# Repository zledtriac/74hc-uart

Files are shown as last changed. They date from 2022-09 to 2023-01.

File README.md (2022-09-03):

# 74hc-uart
In this project, you can find a schematics and descriptions for an asynchronous serial transmitter and receiver with 74hcxxx ICs. The circuits can be used for diy and old cpus where there is no support for UART, or you can just check the schematics to get an idea how an UART could be implemented in microcontrollers. It could be useful for VHDL designs.

## Transmitter
You can find the schematics and a detailed description of the serial transmitter in the ./hardware/transmitter folder.

## Receiver
Coming soon!

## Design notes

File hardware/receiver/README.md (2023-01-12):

# Receiver
This is the receiver. It's only consists of 6 ICs. Actually 5 because U6 the 74HC244 IC can be left out, but with the current configuration it can 
be operated manually for demonstrations.

The receiver can receive a serial data transmission with **1 start bit, 8bit data without parity and 1 stop bit** on the end, with 9600 baude rate.

## Operation
The receiver has 3 pin headers for selecting the mode of operation (J4, J5, J6), before powering the receiver up, **please check the jumper positions, 
because the receiver can't operate in a circuit if the receiver is in manual operation mode.**

The receiver needs a 5V power supply to work, the power pins can be found on the Control header (J2) pin 1 - VCC, pin 2 - GND. After powering up the
receiver, due to the random behaviour of the U5A and U5B (74HC74) D flip-flops, it is possible that the cicuit will load a random data in the output 
register. It is recommanded to wait one full transmition time after power up and read the output register in order to clear the data ready signaling 
U5B D flip-flop.

The Control header (J2) has two other pins for control, pin 4 - !RD, and pin 7 - Ready. The !RD is an active-low input and this input enables the 
output shift register's tri-state output drivers so the received data will be present on the output.
The Ready is an output which will turns on when the data is received and ready to read.

When the RX input goes low, it will start the colock divider and if the input is held low for more than half the time of one bit then U5B (74HC74) 
D flip-flop will be set, and the Input trigger will lock on the signal and keeps the clock divider running. When the clock divider is running it means 
that the Bit counter and the Output shift register will receive a clock signal, and the data reception sequence is in progress. When the Q3 output on 
the Bit counter goes high, it will stops the Clock divider and the circuit will wait until the RX input goes back to high, and when the RX input went 
high it will resets the Input trigger and load the received data into the U4 (74HC595) output register and sets the U5A (74HC74) D flip-flop so the 
Ready output will turn to high.

The Output data register can be read at the same time when the data reception sequence is running because the output data register only updates when 
the data reception sequence is finished. But if the data is not readed befor the second reception finishes it will overwrite the data in the output 
register so the previous data will be lost.

## Manual operation
To use the circuit in a manual operation mode, set the jumper on the J5 pin header to enable the output of the U6 (74HC244) IC so the data on the 
output can be seen on the LED bar. If you want to use the button as a read signal then bridge the 1-2 pins on the J6 Mode select pin header. Or if you 
want to see the received data immediatelly, bridge the 3-4 pins in the J6 Mode select pin header.

## Oscillator
The oscillator is made out of two schmitt-triggered NAND gate of the U1 (74HC132) IC. With the 560pF C1 capacitor and the 10kOhm R1 plus the 10kOhm RV1 trimmer 
potentiometer this oscillator can be adjusted between 107kHz and 214kHz. The oscillator's frequency is not equal to the baud rate, because the sampling clock is
generated with the U2 (74HC191) counter IC which is in this case act as a clock divider. The Q3 output of the U2 (74HC191) IC will give a square wave signal with 
16th of the input frequency. So the equation for the baudrate is:
```
baud_rate = input_freq / 16
```
So the frequency of the oscillator should be 153.6kHz for a 9600 baud rate.\
For tuning the oscillator, a simple digital multimeter with frequency measuring capability is enough.

The J4 Clock select pin header can be used to fed external clock signal into the circuit. Just unplug the bridge from the 2-3 pins and connect the external clock 
signal the pin 3. The pin 4 can be used as a grounding point.

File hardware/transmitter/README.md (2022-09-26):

# Transmitter
This is the transmitter. It's only consists of 6 ICs. Actually 5 because U6 the 74HC244 IC can be left out, but with the current configuration it can 
be operated manually for demonstrations.

The transmitter transmits the data with **1 start bit, 8bit data without parity and 1 stop bit** on the end, with 9600 baud rate.

## Operation
The transmitter has 3 pin headers for selecting the mode of operation (J3, J5, J6), before powering the transmitter up, **please check the jumper positions, 
because the transmitter can't operate in a circuit if the transmitter is in manual operation mode.**

The transmitter needs a 5V power supply to work, the power pins can be found on the Control header (J4) pin 1 - VCC, pin 2 - GND. After powering up the
transmitter, due to the random behaviour of the set-reset latch made with the U5D and U5C NAND gate (74HC132) and of the U3A and U3B (74HC74) D flip-flops, 
it is possible that the cicuit will transmit a random data on the output.

*If this behaviour can cause issues in the target device, it is recommended to build
an output enable circuit after the U3B pin 9 output, which can be controlled by a switch, delay circuit or from software if the transmitter is connected to a CPU.*

The Control header (J4) has two other pins for control, pin 5 - !WR, and pin 8 - Busy. The !WR is an active-low input and this input starts the data transmission.
The Busy is an output which will be held high while the transmission is going (Short pulse section on *Figure 1.*), or while the !WR input is held low (Long pulse section on *Figure 1.*).

To send data, first set the data on the Data header (J1) then send a low pulse on the !WR pin. This will trigger the Input trigger circuitry. In this stage the output 
of the U5D will turn high, but since the U3A D flip-flop is not set, the inverted output of the U3A D flip-flop is also high, this will set the output of the U4A NAND 
gate to low, this will enables the load pins of the U1 (74HC165) shift register and the U2 (74HC191) counter IC, so the data will be loaded into the U1 shift register 
and the U2 counter IC will be set to 0. There is an extra bit made by the U4B NAND gate and the U3B D flip-flop, in the loading process it will set to one, this extra 
bit is the START bit. Since the U3A D flip-flop's clock input is connected to the main clock signal, the U3A D flip-flop will set and the inverted output of the U3A D 
flip-flop will turn to low.
After this, every clock pulse will shift out the data from U1 (74HC165) shift register, and increment the U2 (74HC191) counter until U2 (74HC191) counter reaches 8.
When the U2 (74HC191) counter reaches 8, the counting will stop and if the !WR input is high, it will reset the Input trigger circuitry, and after this, one clock 
pulse is needed to reset the U3A D flip-flop. So when the next write pulse comes in, the whole process will repeat.

<p align="center">

</p>

## Manual operation
To use the circuit in a manual operation mode, set the jumper on the J3 pin header to bridge the 1-2 pins, and on the J5 pin header to bridge the 2-3 pins. This will 
enables the U6 (74HC244) output so the data set by the SW1 dip switch will be put on the DATA input, and it will connect the SW2 button to the !WR input.
After the data set on the SW1 dip switch, the data sending can be initiated by pressing the SW2 button.

**please note that if the circuit is in manual operation mode, the DATA input will be driven by the U6 (74HC244) output and the !WR input will connected to the SW2 
button, so it can't be used in other circuits!**

## Oscillator
The oscillator is made out of two schmitt-triggered NAND gate of the U4 (74HC132) IC. With the 10nF C7 capacitor and the 10kOhm R5 plus the 10kOhm RV1 trimmer 
potentiometer this oscillator can be adjusted between 6kHz and 12kHz. The oscillator's frequency is equal to the baud rate, so for the 9600 baud rate set the 
oscillator to 9.6kHz. For the tuning, a simple digital multimeter with frequency measuring capability is enough.

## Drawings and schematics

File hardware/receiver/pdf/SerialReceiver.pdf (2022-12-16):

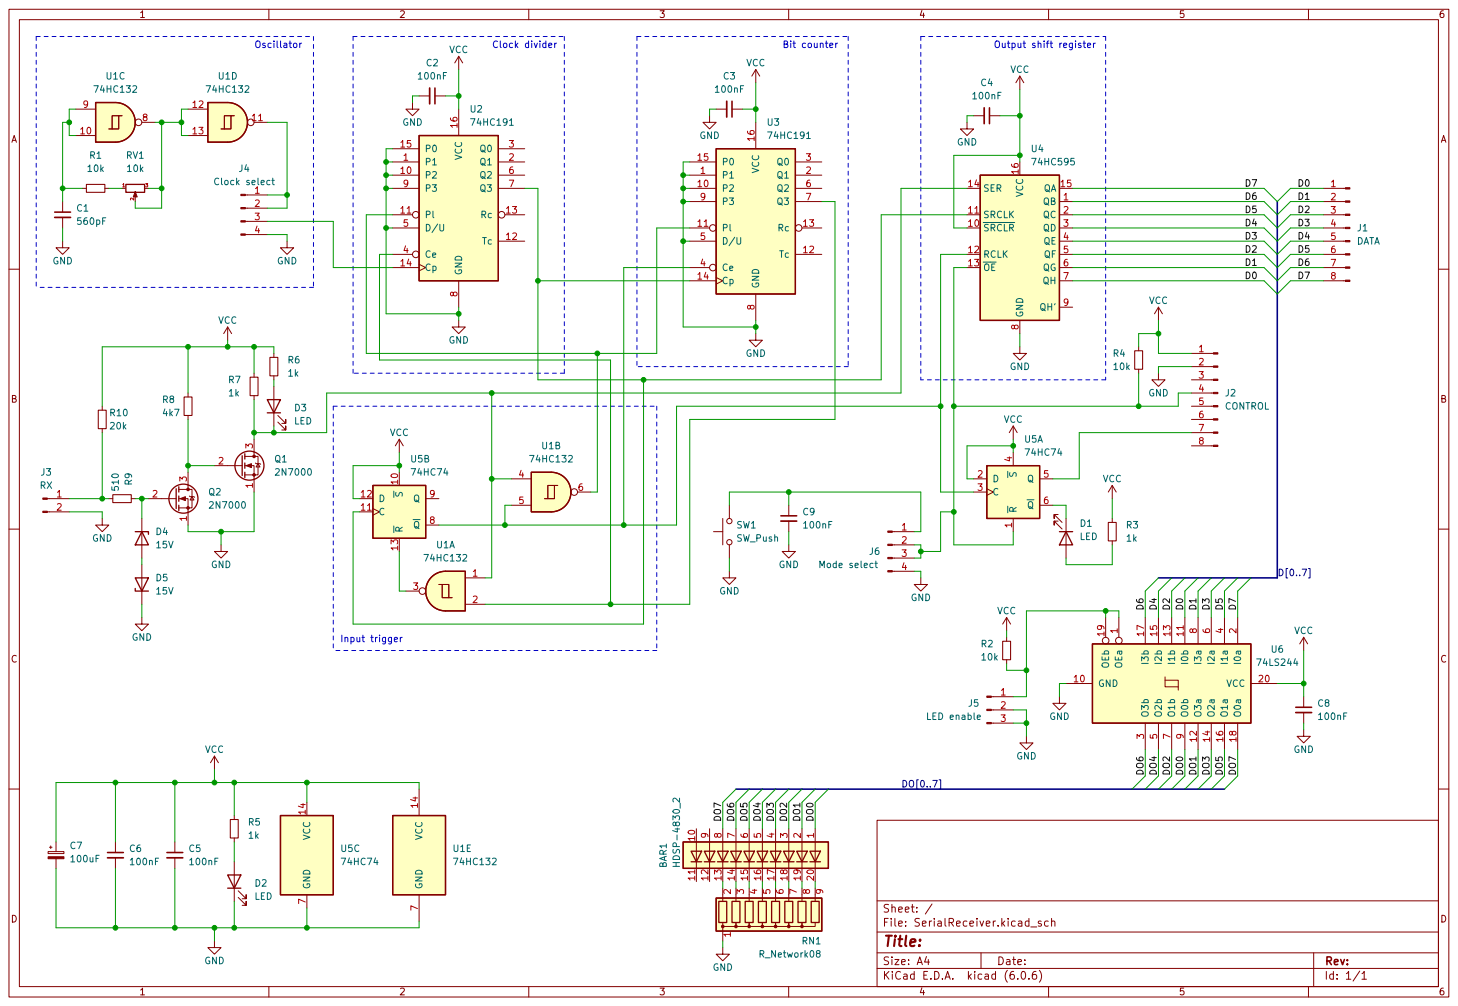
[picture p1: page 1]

File: SerialReceiver.kicad_sch Sheet: / VCC 14 GND

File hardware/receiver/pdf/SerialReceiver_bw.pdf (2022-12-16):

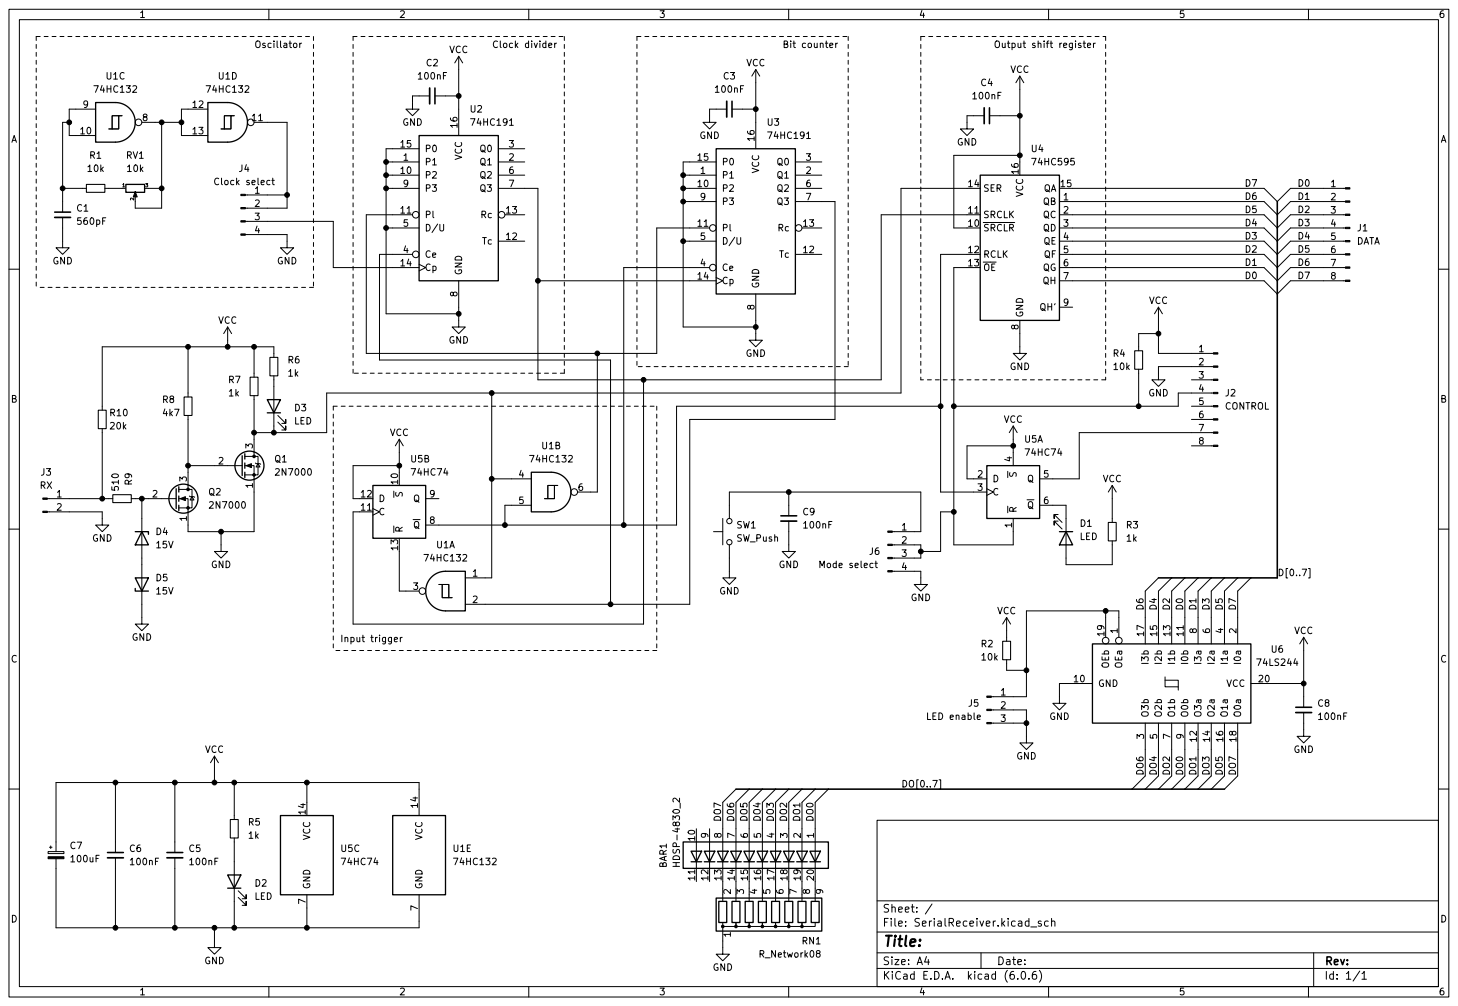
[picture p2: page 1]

File: SerialReceiver.kicad_sch Sheet: / VCC 14 GND

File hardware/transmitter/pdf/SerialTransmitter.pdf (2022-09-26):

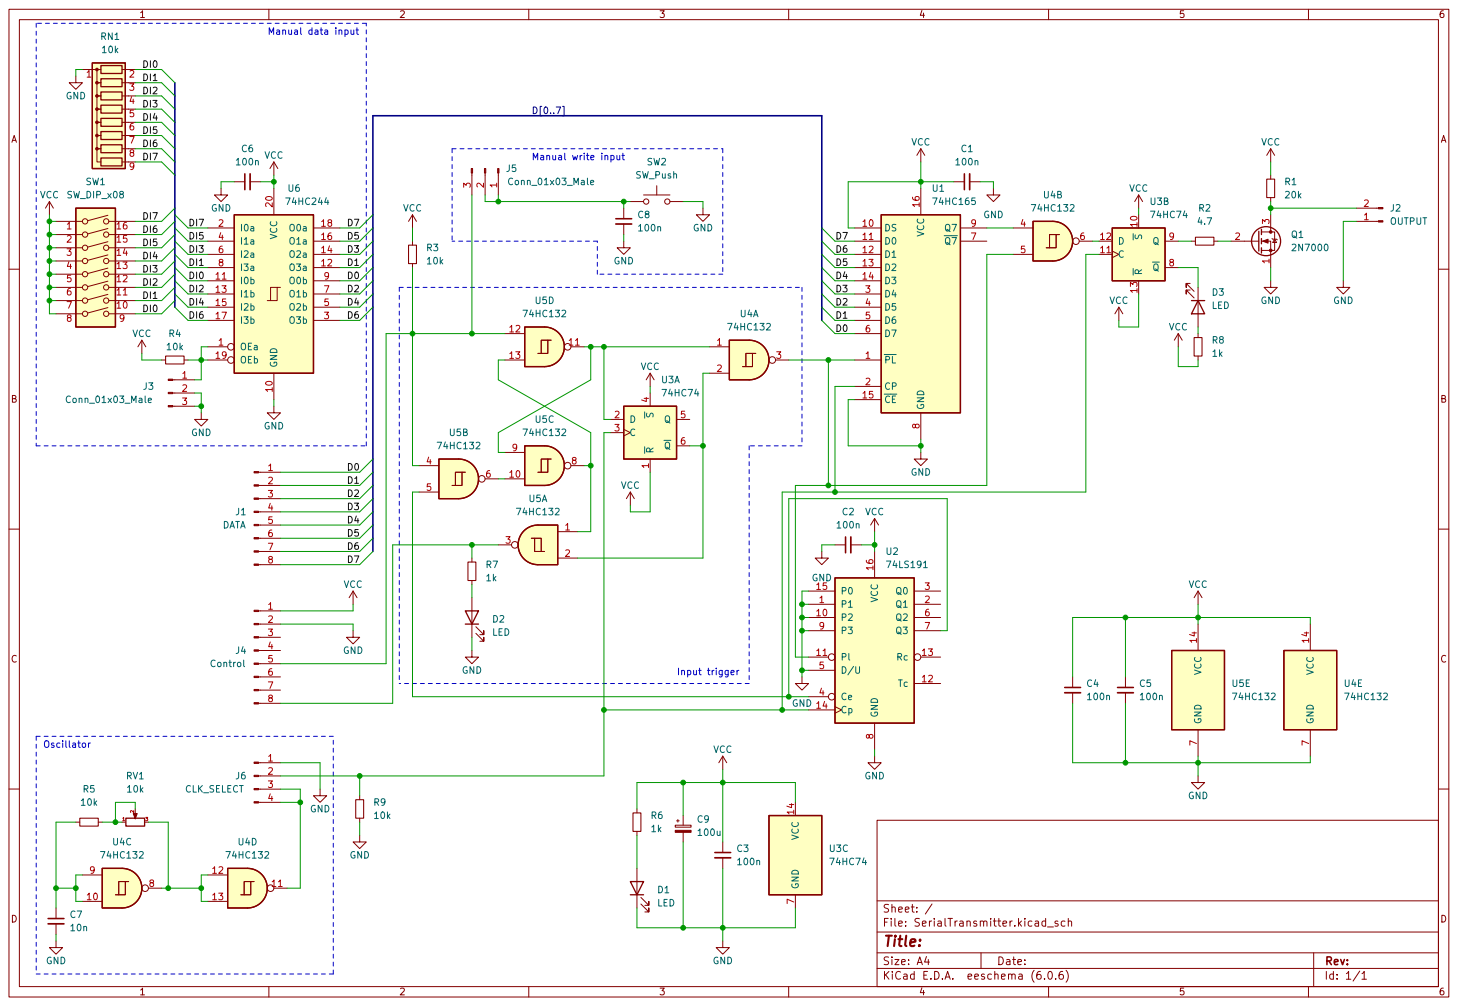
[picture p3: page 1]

File: SerialTransmitter.kicad_sch Sheet: / VCC

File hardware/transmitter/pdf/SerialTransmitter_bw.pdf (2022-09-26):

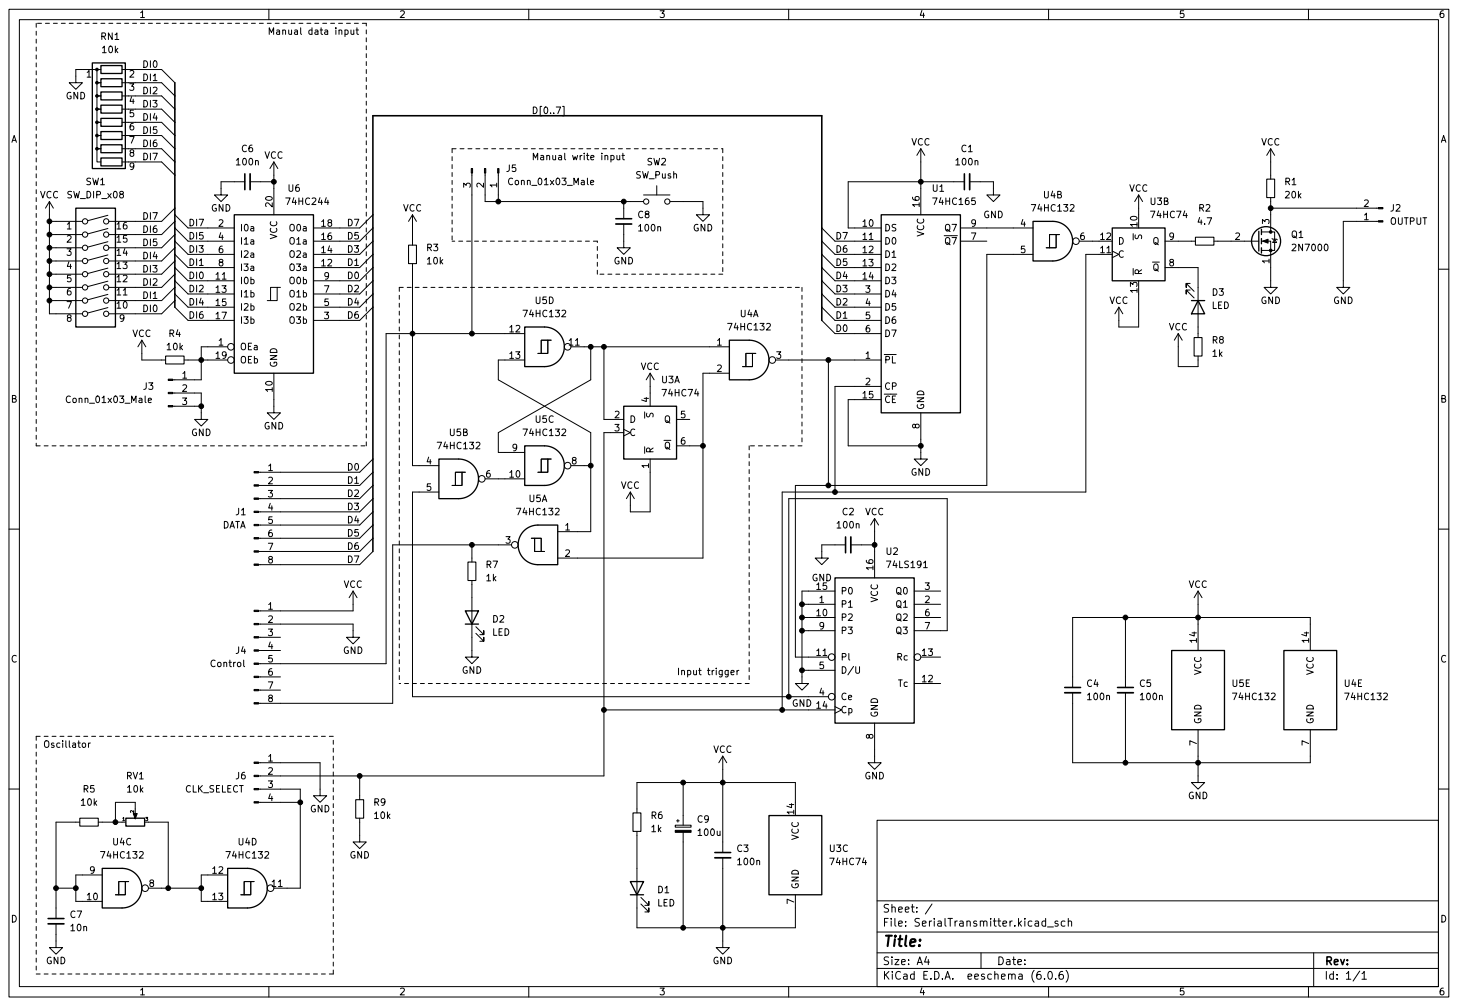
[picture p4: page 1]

File: SerialTransmitter.kicad_sch Sheet: / VCC

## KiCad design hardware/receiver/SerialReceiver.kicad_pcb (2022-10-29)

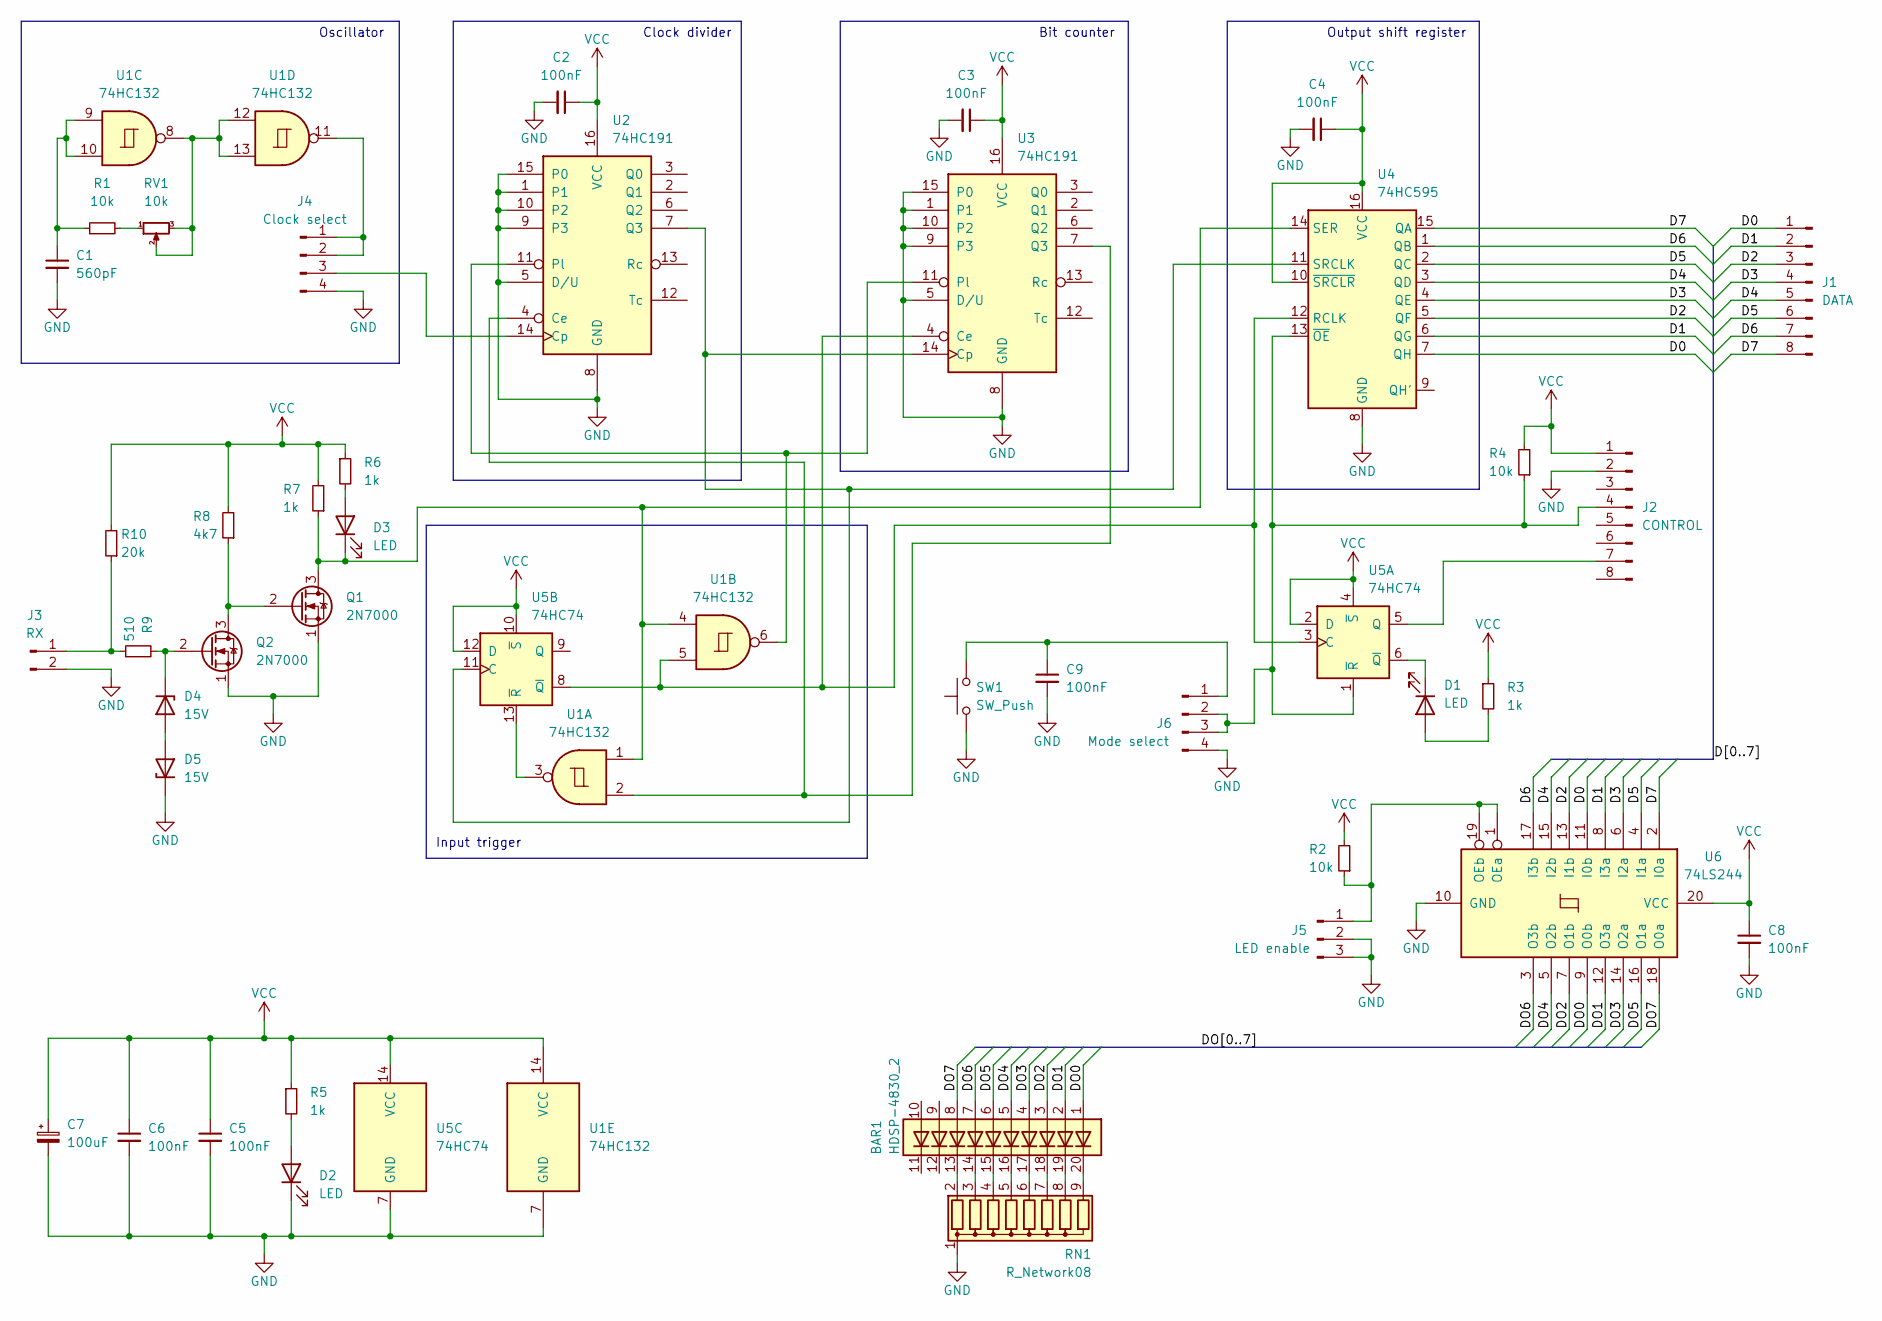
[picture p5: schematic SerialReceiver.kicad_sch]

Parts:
BAR1: HDSP-4830_2; DIP-20_W7.62mm_Socket
C1: 560pF; C_Disc_D3.0mm_W2.0mm_P2.50mm
C2, C3, C4, C5, C6, C8, C9: 100nF; C_Disc_D3.0mm_W2.0mm_P2.50mm
C7: 100uF; CP_Radial_D6.3mm_P2.50mm
D1, D2, D3: LED; LED_D3.0mm
D4, D5: 15V; D_DO-35_SOD27_P7.62mm_Horizontal
J1: DATA; PinHeader_1x08_P2.54mm_Horizontal
J2: CONTROL; PinHeader_1x08_P2.54mm_Horizontal
J3: RX; PinHeader_1x02_P2.54mm_Horizontal
J4: Clock select; PinHeader_1x04_P2.54mm_Vertical
J5: LED enable; PinHeader_1x03_P2.54mm_Vertical
J6: Mode select; PinHeader_1x04_P2.54mm_Vertical
Q1, Q2: 2N7000; TO-92_Inline_Wide
R1, R2, R4: 10k; R_Axial_DIN0207_L6.3mm_D2.5mm_P10.16mm_Horizontal
R3, R5, R6, R7: 1k; R_Axial_DIN0207_L6.3mm_D2.5mm_P10.16mm_Horizontal
R8: 4k7; R_Axial_DIN0207_L6.3mm_D2.5mm_P10.16mm_Horizontal
R9: 510; R_Axial_DIN0207_L6.3mm_D2.5mm_P10.16mm_Horizontal
R10: 20k; R_Axial_DIN0207_L6.3mm_D2.5mm_P10.16mm_Horizontal
RN1: R_Network08; R_Array_SIP9
RV1: 10k; Potentiometer_Bourns_3296W_Vertical
SW1: SW_Push; SW_PUSH_6mm
U1: 74HC132; DIP-14_W7.62mm
U2, U3: 74HC191; DIP-16_W7.62mm
U4: 74HC595; DIP-16_W7.62mm
U5: 74HC74; DIP-14_W7.62mm
U6: 74LS244; DIP-20_W7.62mm

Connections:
/D0: J1.1, U4.7 (QH), U6.11 (I0b)
/D1: J1.2, U4.6 (QG), U6.8 (I3a)
/D2: J1.3, U4.5 (QF), U6.13 (I1b)
/D3: J1.4, U4.4 (QE), U6.6 (I2a)
/D4: J1.5, U4.3 (QD), U6.15 (I2b)
/D5: J1.6, U4.2 (QC), U6.4 (I1a)
/D6: J1.7, U4.1 (QB), U6.17 (I3b)
/D7: J1.8, U4.15 (QA), U6.2 (I0a)
/DO0: BAR1.1 (A), U6.9 (O0b)
/DO1: BAR1.2 (A), U6.12 (O3a)
/DO2: BAR1.3 (A), U6.7 (O1b)
/DO3: BAR1.4 (A), U6.14 (O2a)
/DO4: BAR1.5 (A), U6.5 (O2b)
/DO5: BAR1.6 (A), U6.16 (O1a)
/DO6: BAR1.7 (A), U6.3 (O3b)
/DO7: BAR1.8 (A), U6.18 (O0a)
GND: C1.2, C2.2, C3.2, C4.2, C5.2, C6.2, C7.2, C8.2, C9.2, D2.1 (K), D5.1 (K), J2.2, J3.2, J4.4, J5.2, J5.3, J6.4, Q1.1 (S), Q2.1 (S), RN1.1 (common), SW1.1, U1.7 (GND), U2.1, U2.5 (D/U), U2.8 (GND), U2.9 (P3), U2.10 (P2), U2.15 (P0), U3.1, U3.5 (D/U), U3.8 (GND), U3.9 (P3), U3.10 (P2), U3.15 (P0), U4.8 (GND), U5.7 (GND), U6.10 (GND)
unnamed: BAR1.13 (K), RN1.2 (R1)
unnamed: BAR1.14 (K), RN1.3 (R2)
unnamed: BAR1.15 (K), RN1.4 (R3)
unnamed: BAR1.16 (K), RN1.5 (R4)
unnamed: BAR1.17 (K), RN1.6 (R5)
unnamed: BAR1.18 (K), RN1.7 (R6)
unnamed: BAR1.19 (K), RN1.8 (R7)
unnamed: BAR1.20 (K), RN1.9 (R8)
unnamed: C1.1, R1.1, U1.9, U1.10
unnamed: C9.1, J6.1, SW1.2
unnamed: D1.1 (K), U5.6 (~Q)
unnamed: D1.2 (A), R3.2
unnamed: D2.2 (A), R5.2
unnamed: D3.1 (K), Q1.3 (D), R7.1, U1.1, U1.4, U4.14 (SER)
unnamed: D3.2 (A), R6.2
unnamed: D4.1 (K), Q2.2 (G), R9.2
unnamed: D4.2 (A), D5.2 (A)
unnamed: J2.4, J6.2, J6.3, R4.1, U4.13 (~OE), U5.1 (~R)
unnamed: J2.7, U5.5 (Q)
unnamed: J3.1, R9.1, R10.1
unnamed: J4.1, J4.2, U1.11
unnamed: J4.3, U2.14 (Cp)
unnamed: J5.1, R2.1, U6.1 (OEa), U6.19 (OEb)
unnamed: Q1.2 (G), Q2.3 (D), R8.1
unnamed: R1.2, RV1.1
unnamed: U1.2, U2.4 (Ce), U3.7 (Q3)
unnamed: U1.3, U5.13 (~R)
unnamed: U1.5, U3.4 (Ce), U4.12 (RCLK), U5.3 (C), U5.8 (~Q)
unnamed: U1.6, U2.11 (Pl), U3.11 (Pl)
unnamed: RV1.2, RV1.3, U1.8, U1.12, U1.13
unnamed: U2.7 (Q3), U3.14 (Cp), U4.11 (SRCLK), U5.11 (C)
VCC: C2.1, C3.1, C4.1, C5.1, C6.1, C7.1, C8.1, J2.1, R2.2, R3.1, R4.2, R5.1, R6.1, R7.2, R8.2, R10.2, U1.14 (VCC), U2.16 (VCC), U3.16 (VCC), U4.10 (~SRCLR), U4.16 (VCC), U5.2 (D), U5.4 (~S), U5.10 (~S), U5.12 (D), U5.14 (VCC), U6.20 (VCC)

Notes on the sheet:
Bit counter
Clock divider
Oscillator
Output shift register
Input trigger

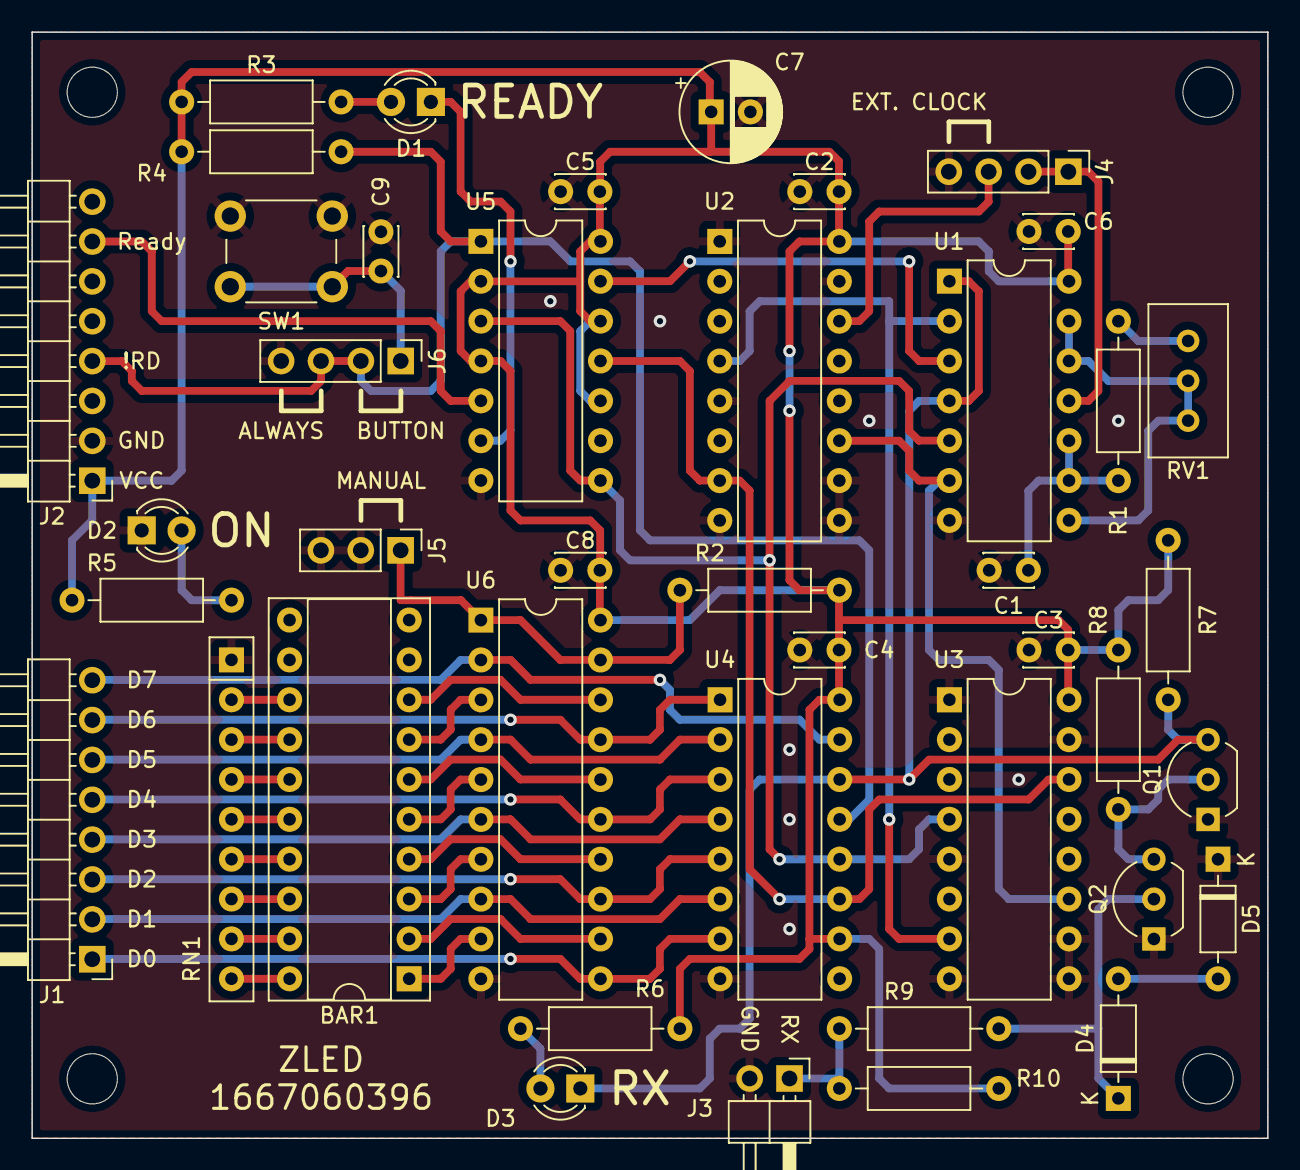
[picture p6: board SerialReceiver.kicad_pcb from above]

Board: 2 copper layers, 78.7 x 70.5 mm, 42 parts (0 on the bottom side), 49 nets.

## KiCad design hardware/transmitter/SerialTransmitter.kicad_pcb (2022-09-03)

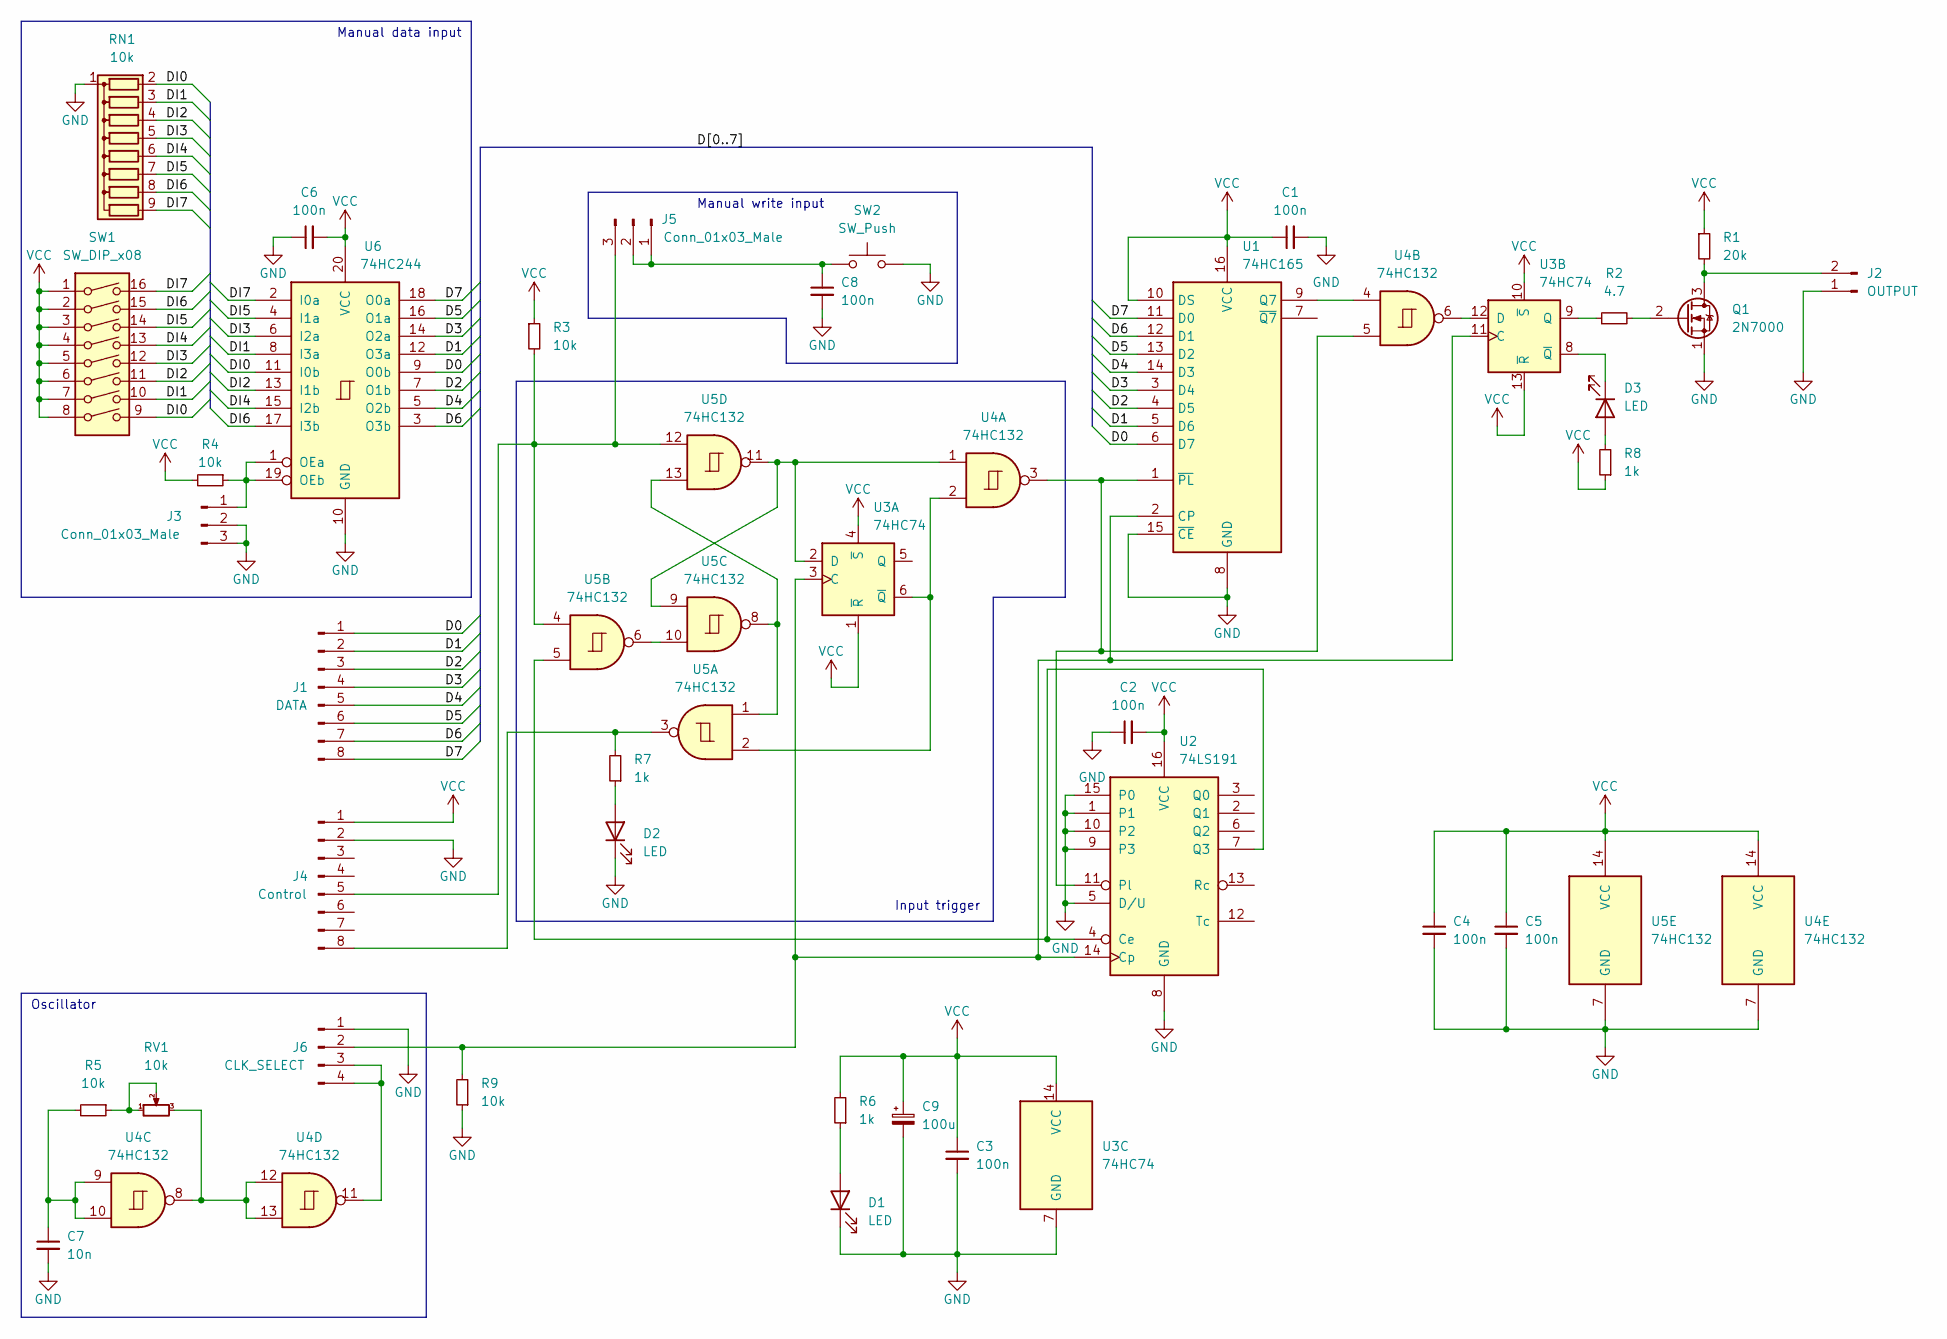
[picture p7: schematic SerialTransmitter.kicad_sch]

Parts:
C1, C2, C3, C4, C5, C6, C8: 100n; C_Disc_D3.0mm_W2.0mm_P2.50mm
C7: 10n; C_Disc_D3.0mm_W2.0mm_P2.50mm
C9: 100u; CP_Radial_D6.3mm_P2.50mm
D1, D2, D3: LED; LED_D3.0mm
J1: DATA; PinHeader_1x08_P2.54mm_Horizontal
J2: OUTPUT; PinHeader_1x02_P2.54mm_Horizontal
J3, J5: Conn_01x03_Male; PinHeader_1x03_P2.54mm_Vertical
J4: Control; PinHeader_1x08_P2.54mm_Horizontal
J6: CLK_SELECT; PinHeader_1x04_P2.54mm_Vertical
Q1: 2N7000; TO-92_Inline
R1: 20k; R_Axial_DIN0207_L6.3mm_D2.5mm_P10.16mm_Horizontal
R2: 4.7; R_Axial_DIN0207_L6.3mm_D2.5mm_P10.16mm_Horizontal
R3, R4, R5, R9: 10k; R_Axial_DIN0207_L6.3mm_D2.5mm_P10.16mm_Horizontal
R6, R7, R8: 1k; R_Axial_DIN0207_L6.3mm_D2.5mm_P10.16mm_Horizontal
RN1: 10k; R_Array_SIP9
RV1: 10k; Potentiometer_Bourns_3296W_Vertical
SW1: SW_DIP_x08; DIP-16_W7.62mm_Socket
SW2: SW_Push; SW_PUSH_6mm
U1: 74HC165; DIP-16_W7.62mm
U2: 74LS191; DIP-16_W7.62mm
U3: 74HC74; DIP-14_W7.62mm
U4, U5: 74HC132; DIP-14_W7.62mm
U6: 74HC244; DIP-20_W7.62mm

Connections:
/D0: J1.1, U1.6 (D7), U6.9 (O0b)
/D1: J1.2, U1.5 (D6), U6.12 (O3a)
/D2: J1.3, U1.4 (D5), U6.7 (O1b)
/D3: J1.4, U1.3 (D4), U6.14 (O2a)
/D4: J1.5, U1.14 (D3), U6.5 (O2b)
/D5: J1.6, U1.13 (D2), U6.16 (O1a)
/D6: J1.7, U1.12 (D1), U6.3 (O3b)
/D7: J1.8, U1.11 (D0), U6.18 (O0a)
/DI0: RN1.2 (R1), SW1.9, U6.11 (I0b)
/DI1: RN1.3 (R2), SW1.10, U6.8 (I3a)
/DI2: RN1.4 (R3), SW1.11, U6.13 (I1b)
/DI3: RN1.5 (R4), SW1.12, U6.6 (I2a)
/DI4: RN1.6 (R5), SW1.13, U6.15 (I2b)
/DI5: RN1.7 (R6), SW1.14, U6.4 (I1a)
/DI6: RN1.8 (R7), SW1.15, U6.17 (I3b)
/DI7: RN1.9 (R8), SW1.16, U6.2 (I0a)
unnamed: C7.1, R5.2, U4.9, U4.10
unnamed: C8.1, J5.1, J5.2, SW2.1
unnamed: D1.2 (A), R6.1
unnamed: D2.2 (A), R7.1
unnamed: D3.1 (K), U3.8 (~Q)
unnamed: D3.2 (A), R8.2
unnamed: J2.2, Q1.3 (D), R1.2
unnamed: J3.1, R4.1, U6.1 (OEa), U6.19 (OEb)
unnamed: J4.5, J5.3, R3.2, U5.4, U5.12
unnamed: J6.2, R9.2, U1.2 (CP), U2.14 (Cp), U3.3 (C), U3.11 (C)
unnamed: J6.3, J6.4, U4.11
unnamed: Q1.2 (G), R2.2
unnamed: R2.1, U3.9 (Q)
unnamed: R5.1, RV1.1, RV1.2
unnamed: J4.8, R7.2, U5.3
unnamed: RV1.3, U4.8, U4.12, U4.13
unnamed: U1.1 (~PL), U2.11 (Pl), U4.3, U4.5
unnamed: U1.9 (Q7), U4.4
unnamed: U2.4 (Ce), U2.7 (Q3), U5.5
unnamed: U3.2 (D), U4.1, U5.9, U5.11
unnamed: U3.6 (~Q), U4.2, U5.2
unnamed: U3.12 (D), U4.6
unnamed: U5.1, U5.8, U5.13
unnamed: U5.6, U5.10

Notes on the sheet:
Input trigger
Oscillator
Manual data input
Manual write input

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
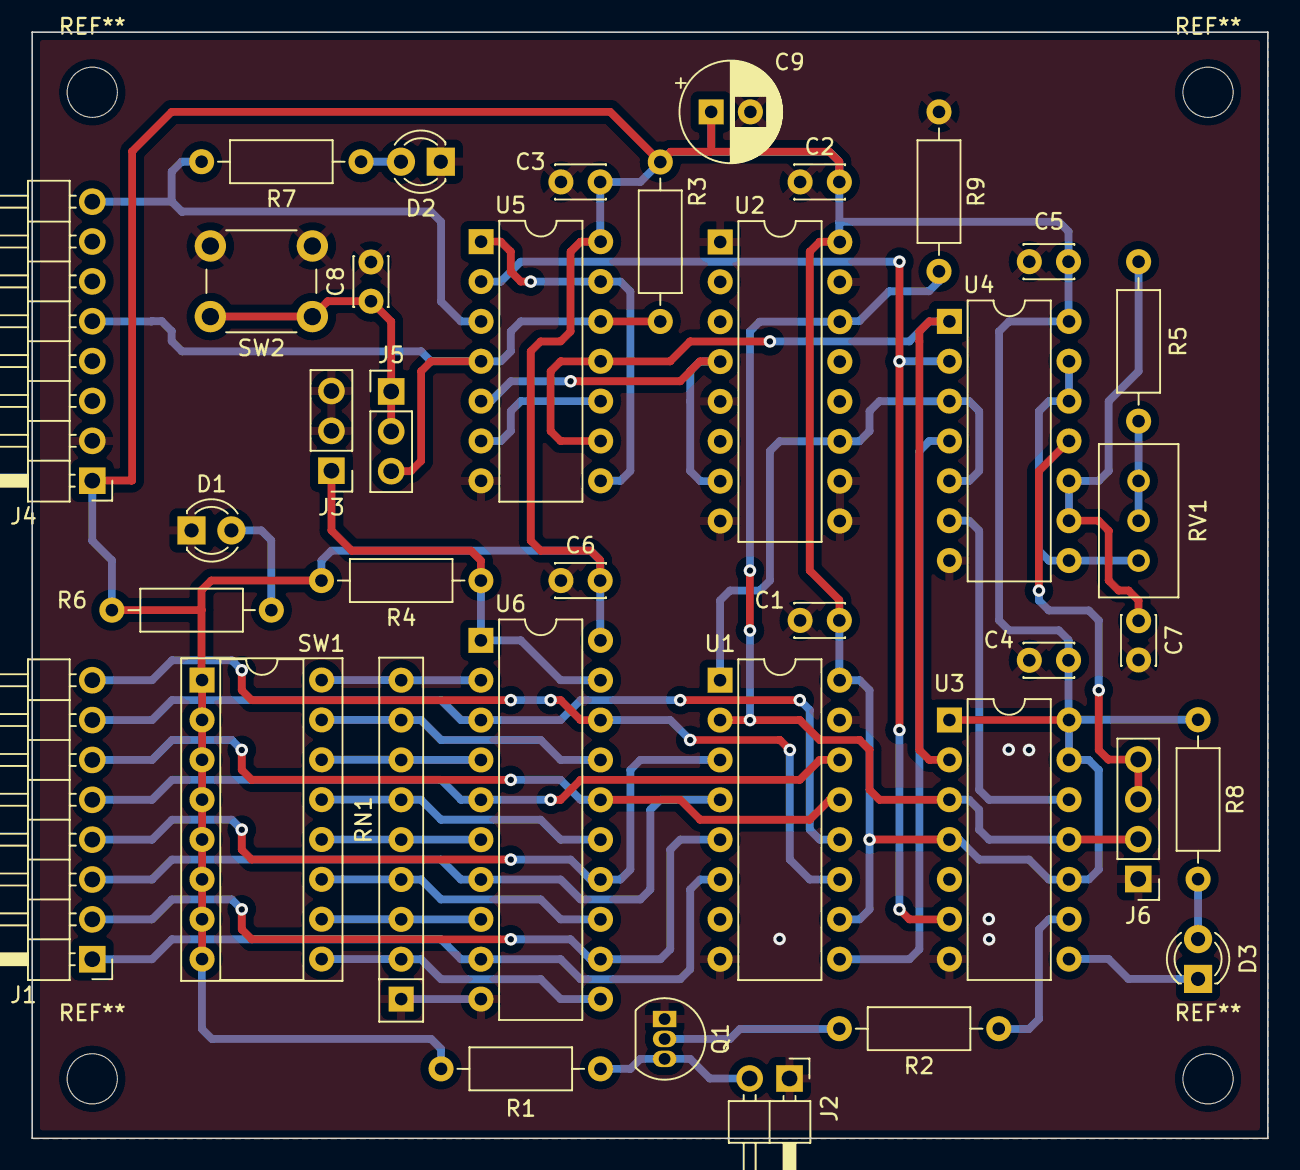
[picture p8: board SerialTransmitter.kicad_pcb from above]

Board: 2 copper layers, 78.7 x 70.5 mm, 38 parts (0 on the bottom side), 42 nets.

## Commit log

2022-08-24 Upload project files.
    [SerialTransmitter.kicad_pcb, SerialTransmitter.kicad_sch]
2022-09-03 Added the receiver project files.
    [SerialReceiver.kicad_pcb, SerialReceiver.kicad_sch]
2022-09-03 Added some notes to the schematic, changed the names of the components, moved some parts.
    [SerialTransmitter.kicad_pcb, SerialTransmitter.kicad_sch]
2022-09-26 The schematic has been exported to PDFs, and added timing diagram files.
2022-09-27 Continued the design of the receiver.
    [SerialReceiver.kicad_sch]
2022-09-28 Setting the names and the values of the receiver's components.
    [SerialReceiver.kicad_sch]
2022-10-02 Starting the PCB design.
    [SerialReceiver.kicad_pcb, SerialReceiver.kicad_sch]
2022-10-04 Changed the layout of the schematic for better wiring.
    [SerialReceiver.kicad_pcb, SerialReceiver.kicad_sch]
2022-10-23 Made an RX input protection, and almost finished the PCB.
    [SerialReceiver.kicad_pcb, SerialReceiver.kicad_sch]
2022-10-23 Input protection is now on the PCB.
    [SerialReceiver.kicad_pcb, SerialReceiver.kicad_sch]
2022-10-23 The receiver's PCB is finished.
    [SerialReceiver.kicad_pcb, SerialReceiver.kicad_sch]
2022-10-26 The schematic and the PCB is finished.
    [SerialReceiver.kicad_pcb, SerialReceiver.kicad_sch]
2022-10-29 Minor fixes on the receiver's PCB.
    [SerialReceiver.kicad_pcb]
2022-12-16 Exported the Schematics to PDF for the receiver.
